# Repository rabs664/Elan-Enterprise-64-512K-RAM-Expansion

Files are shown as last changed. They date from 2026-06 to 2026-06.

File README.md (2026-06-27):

# Elan-Enterprise-64-512K-RAM-Expansion

512K EP RAM

>[!CAUTION]
>USE AT YOUR OWN RISK.
>There is always the risk that this 512k RAM Expansion could cause harm to your Enterprise. Although I have tested the 512K RAM Expansion, there is no guarantee that it will work properly under all circumstances.
>
>I am not an Enterprise Expert and still learning about this machine. What you see here is an intepretation of what I have found on the web, see the acknowledgements.

>[!WARNING]
>There is not a lot of room under the keyboard and the jumper wire connectors are a tight fit. There is probably a better solution to this.
>
> Also the EXP1 connector does not have standard spacing and you have to use two separate headers.
>
> 

## Project History
### 27 June 2026
First Releae

## Acknowledgements
- [Supid Humans Inc EP RAM](https://github.com/StupidHumansInc/EP_RAM)
- [Andra Santos](https://github.com/andrastantos/enterprise_mem_extender)

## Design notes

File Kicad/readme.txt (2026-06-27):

This folder contains the Kicad project files and gerbers.

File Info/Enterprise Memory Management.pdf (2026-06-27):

The Enterprise has a 22-bit address space (A0 to A21) giving 4MB of addressable space!

The Z80 address space is divided into 16KB “Pages” (numbered 0-3) where A14 and A15 select four 8-bit “Segment” registers in “DAVE”.

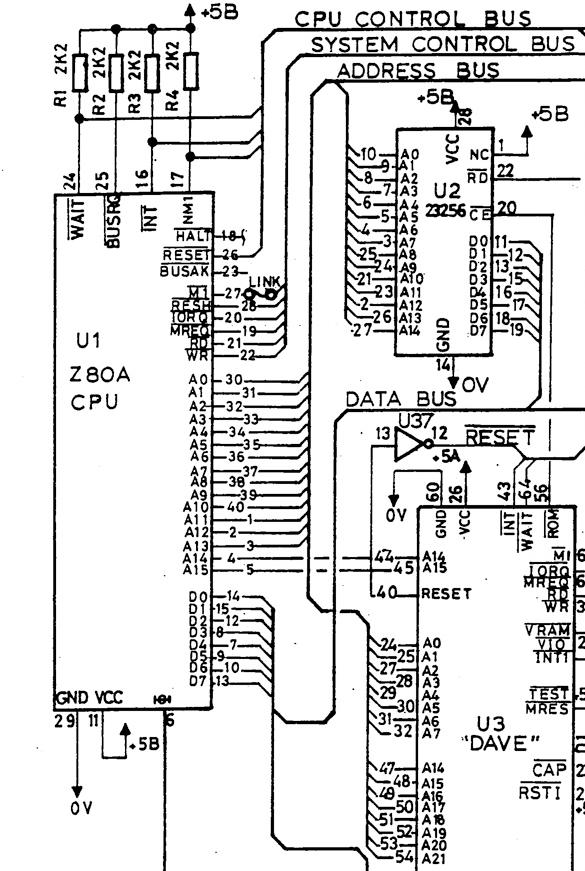
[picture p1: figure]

The Enterprise 4MB address space is divided into 256 16K “segments”. Each “Segment” has a number, 00h-FFh.

A0-A13 + 8-bits, from the “Segment” registers, generate the 22-bit address.

Certain “Segments” are predefined

Internal 32K ROM | 00h-01h
64K Cartridge Slot | 04h-07h
Internal 64K DRAM | FCh-FFh
2 nd Internal 64K DRAM | F8h-FBh

There is Z80 I/O port associated with each “Segment” register in “DAVE” which allows the “Segment” number to be set for each “page”.
Page | Address | Port
0 | 0000h-3FFFh | B0h
1 | 4000h-7FFFh | B1h
2 | 8000h-BFFFh | B2h
3 | C000h-FFFFh | B3h

Any “Segment” can be mapped to any “Page” by writing the “Segment” number to the IO port for the respective “Page”.

Using 512KB SRAM (AS6C4008) with 19 address lines (A0 to A18), the “Segments” are as below;

Segment | A21 | A20 | A19 | A18 | A17 | A16 | A15 | A14 | Note
FF | 1 | 1 | 1 | 1 | 1 | 1 | 1 | 1 | Internal DRAM
FE | 1 | 1 | 1 | 1 | 1 | 1 | 1 | 0 | Internal DRAM
FD | 1 | 1 | 1 | 1 | 1 | 1 | 0 | 1 | Internal DRAM
FC | 1 | 1 | 1 | 1 | 1 | 1 | 0 | 0 | Internal DRAM
FB | 1 | 1 | 1 | 1 | 1 | 0 | 1 | 1 | 512K SRAM
FA | 1 | 1 | 1 | 1 | 1 | 0 | 1 | 0 | 512K SRAM
F9 | 1 | 1 | 1 | 1 | 1 | 0 | 0 | 1 | 512K SRAM
F8 | 1 | 1 | 1 | 1 | 1 | 0 | 0 | 0 | 512K SRAM
F7 | 1 | 1 | 1 | 1 | 0 | 1 | 1 | 1 | 512K SRAM
F6 | 1 | 1 | 1 | 1 | 0 | 1 | 1 | 0 | 512K SRAM
F5 | 1 | 1 | 1 | 1 | 0 | 1 | 0 | 1 | 512K SRAM
F4 | 1 | 1 | 1 | 1 | 0 | 1 | 0 | 0 | 512K SRAM
F3 | 1 | 1 | 1 | 1 | 0 | 0 | 1 | 1 | 512K SRAM
F2 | 1 | 1 | 1 | 1 | 0 | 0 | 1 | 0 | 512K SRAM
F1 | 1 | 1 | 1 | 1 | 0 | 0 | 0 | 1 | 512K SRAM
F0 | 1 | 1 | 1 | 1 | 0 | 0 | 0 | 0 | 512K SRAM
EF | 1 | 1 | 1 | 0 | 1 | 1 | 1 | 1 | 512K SRAM
EE | 1 | 1 | 1 | 0 | 1 | 1 | 1 | 0 | 512K SRAM
ED | 1 | 1 | 1 | 0 | 1 | 1 | 0 | 1 | 512K SRAM
EC | 1 | 1 | 1 | 0 | 1 | 1 | 0 | 0 | 512K SRAM
EB | 1 | 1 | 1 | 0 | 1 | 0 | 1 | 1 | 512K SRAM
EA | 1 | 1 | 1 | 0 | 1 | 0 | 1 | 0 | 512K SRAM
E9 | 1 | 1 | 1 | 0 | 1 | 0 | 0 | 1 | 512K SRAM
E8 | 1 | 1 | 1 | 0 | 1 | 0 | 0 | 0 | 512K SRAM
E7 | 1 | 1 | 1 | 0 | 0 | 1 | 1 | 1 | 512K SRAM
E6 | 1 | 1 | 1 | 0 | 0 | 1 | 1 | 0 | 512K SRAM
E5 | 1 | 1 | 1 | 0 | 0 | 1 | 0 | 1 | 512K SRAM
E4 | 1 | 1 | 1 | 0 | 0 | 1 | 0 | 0 | 512K SRAM
E3 | 1 | 1 | 1 | 0 | 0 | 0 | 1 | 1 | 512K SRAM
E2 | 1 | 1 | 1 | 0 | 0 | 0 | 1 | 0 | 512K SRAM
E1 | 1 | 1 | 1 | 0 | 0 | 0 | 0 | 1 | 512K SRAM
E0 | 1 | 1 | 1 | 0 | 0 | 0 | 0 | 0 | 512K SRAM
DF | 1 | 1 | 0 | 1 | 1 | 1 | 1 | 1 | 512K SRAM
DE | 1 | 1 | 0 | 1 | 1 | 1 | 1 | 0 | 512K SRAM
DD | 1 | 1 | 0 | 1 | 1 | 1 | 0 | 1 | 512K SRAM
DC | 1 | 1 | 0 | 1 | 1 | 1 | 0 | 0 | 512K SRAM
DB | 1 | 1 | 0 | 1 | 1 | 0 | 1 | 1 | No SRAM

Note DF-DC maps over the Internal DRAM “Segments” but with A19 low.

Decoded Address Line signals to drive CE on the 512KB SRAM are as follows; (A21 & A20 & A19 & A18 & A17 & !A16)

# (A21 & A20 & A19 & A18 & !A17)

# (A21 & A20 & A19 & !A18)

# (A21 & A20 & !A19 & A18 & A17 & A16)

Additionally, the Control Lines for a Memory Request and excluding Refresh cycles are required.

!MREQ & REFSH
ChatGPT reduced this but it is easier to follow the above.
!CE=A21 & A20 & !MREQ & RFSH & (A19 & !A18 # A19 & /A17 # A19 & /A16 # /A19 &A18 & A17 &A16)

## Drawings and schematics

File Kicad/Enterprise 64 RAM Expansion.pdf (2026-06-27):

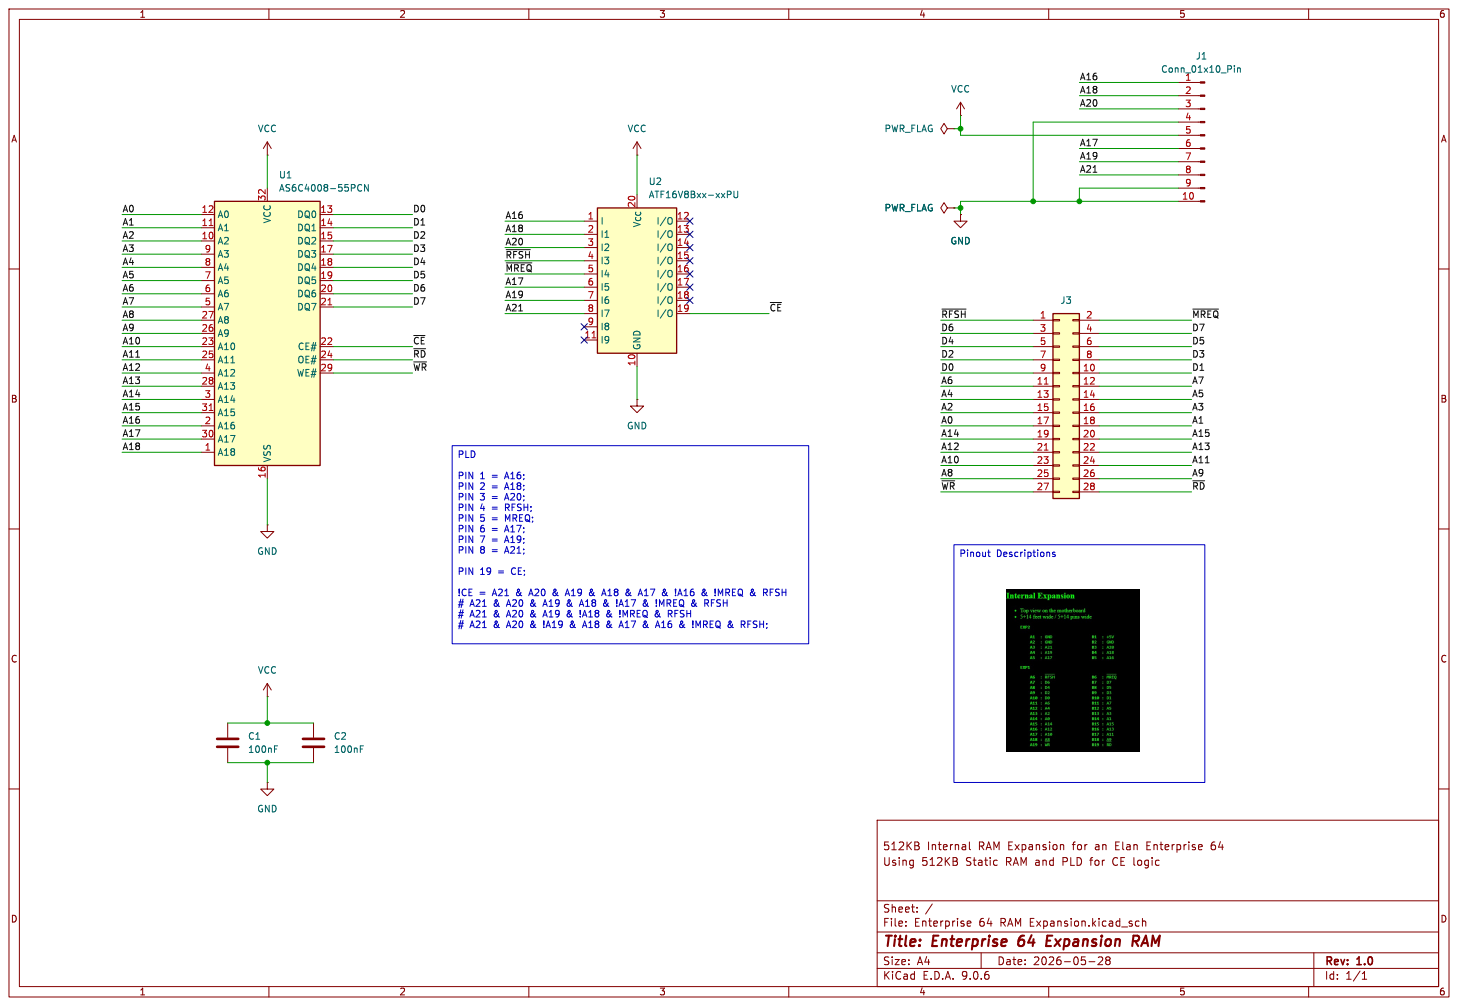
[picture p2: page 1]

PIN 1 = A16; PIN 2 = A18; PIN 3 = A20; PIN 4 = RFSH; PIN 5 = MREQ; PIN 6 = A17; PIN 7 = A19; PIN 8 = A21; PIN 19 = CE;

Id: 1/1 Title: Enterprise 64 Expansion RAM

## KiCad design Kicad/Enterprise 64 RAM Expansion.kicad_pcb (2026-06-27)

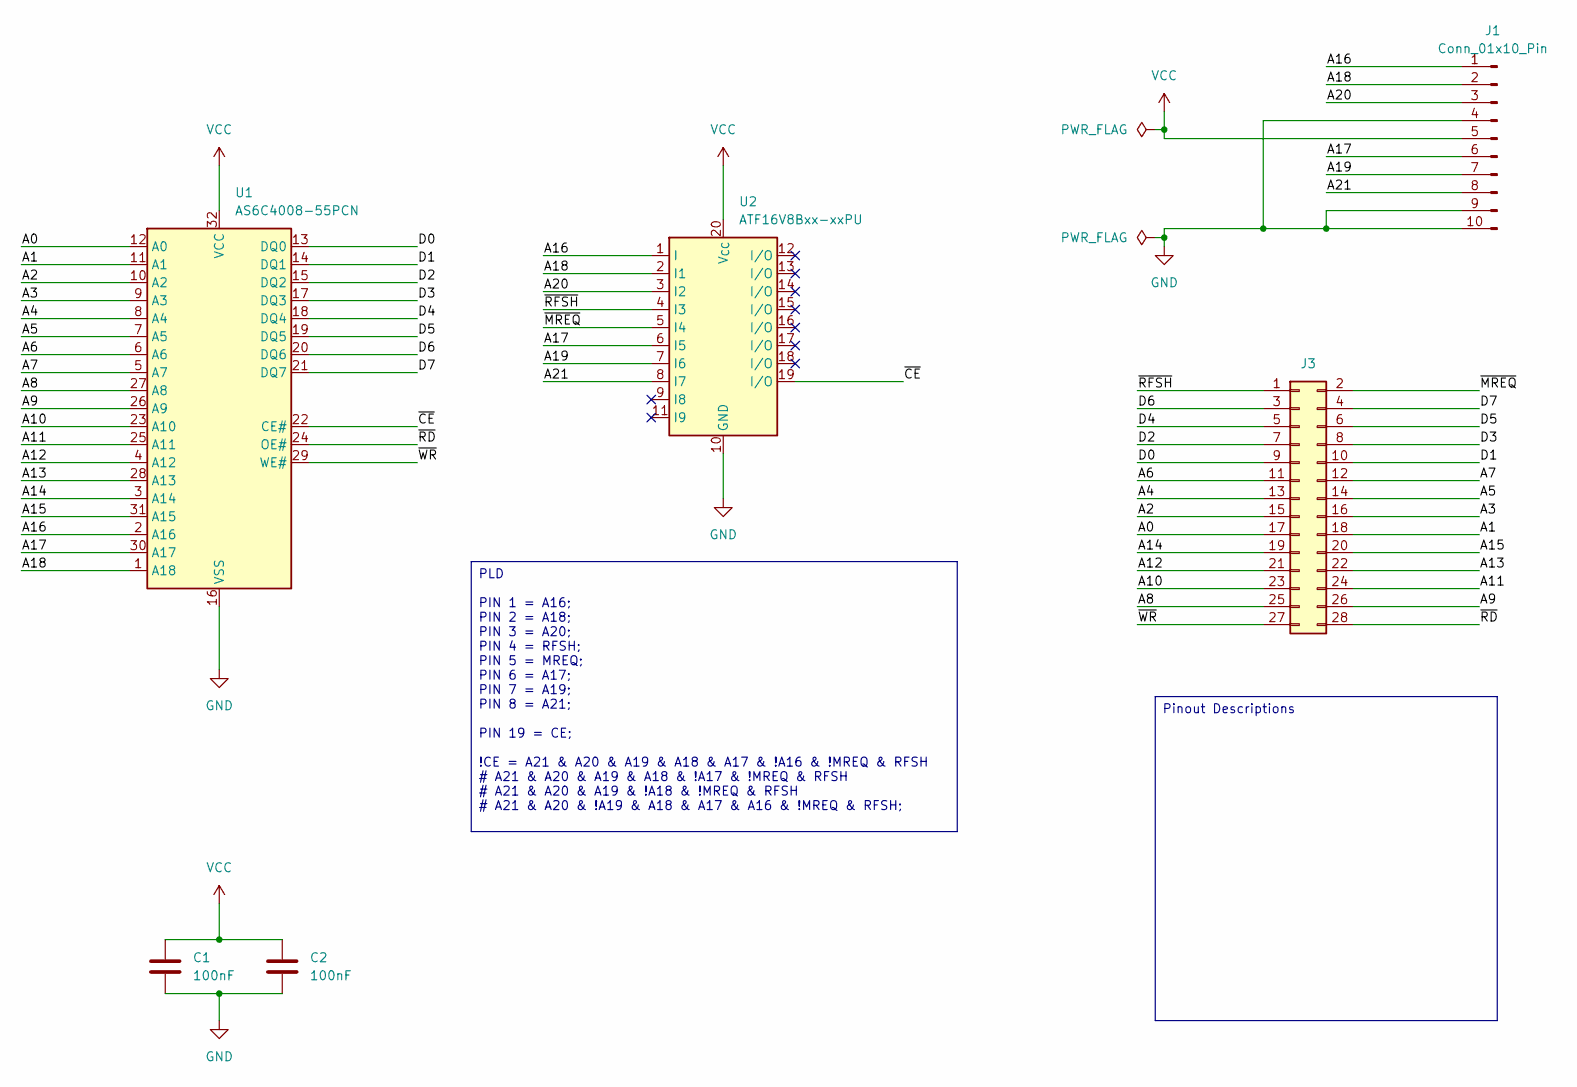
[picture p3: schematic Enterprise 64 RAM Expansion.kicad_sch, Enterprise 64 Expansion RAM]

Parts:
C1, C2: 100nF; C_0805_2012Metric_Pad1.18x1.45mm_HandSolder
J1: Conn_01x10_Pin; PinHeader_1x10_P2.54mm_Horizontal
J3: Conn_02x16_Row_Letter_First; PinSocket_2x14_P2.54mm_Vertical
U1: AS6C4008-55PCN; SOP-32_11.305x20.495mm_P1.27mm
U2: ATF16V8Bxx-xxPU; SOIC-20W_7.5x12.8mm_P1.27mm

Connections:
/A0: J3.17, U1.12 (A0)
/A1: J3.18, U1.11 (A1)
/A2: J3.15, U1.10 (A2)
/A3: J3.16, U1.9 (A3)
/A4: J3.13, U1.8 (A4)
/A5: J3.14, U1.7 (A5)
/A6: J3.11, U1.6 (A6)
/A7: J3.12, U1.5 (A7)
/A8: J3.25, U1.27 (A8)
/A9: J3.26, U1.26 (A9)
/A10: J3.23, U1.23 (A10)
/A11: J3.24, U1.25 (A11)
/A12: J3.21, U1.4 (A12)
/A13: J3.22, U1.28 (A13)
/A14: J3.19, U1.3 (A14)
/A15: J3.20, U1.31 (A15)
/A16: J1.1, U1.2 (A16), U2.1 (I)
/A17: J1.6, U1.30 (A17), U2.6 (I5)
/A18: J1.2, U1.1 (A18), U2.2 (I1)
/A19: J1.7, U2.7 (I6)
/A20: J1.3, U2.3 (I2)
/A21: J1.8, U2.8 (I7)
/D0: J3.9, U1.13 (DQ0)
/D1: J3.10, U1.14 (DQ1)
/D2: J3.7, U1.15 (DQ2)
/D3: J3.8, U1.17 (DQ3)
/D4: J3.5, U1.18 (DQ4)
/D5: J3.6, U1.19 (DQ5)
/D6: J3.3, U1.20 (DQ6)
/D7: J3.4, U1.21 (DQ7)
/~CE: U1.22 (CE#), U2.19 (I/O)
/~MREQ: J3.2, U2.5 (I4)
/~RD: J3.28, U1.24 (OE#)
/~RFSH: J3.1, U2.4 (I3)
/~WR: J3.27, U1.29 (WE#)
GND: C1.2, C2.2, J1.4, J1.9, J1.10, U1.16 (VSS), U2.10 (GND)
VCC: C1.1, C2.1, J1.5, U1.32 (VCC), U2.20 (V_{CC})

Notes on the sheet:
Pinout Descriptions
PLD PIN 1 = A16; PIN 2 = A18; PIN 3 = A20; PIN 4 = RFSH; PIN 5 = MREQ; PIN 6 = A17; PIN 7 = A19; PIN 8 = A21; PIN 19 = CE; !CE = A21 & A20 & A19 & A18 & A17 & !A16 & !MREQ & RFSH # A21 & A20 & A19 & A18 & !A17 & !MREQ & RFSH # A21 & A20 & A19 & !A18 & !MREQ & RFSH # A21 & A20 & !A19 & A18 & A17 & A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

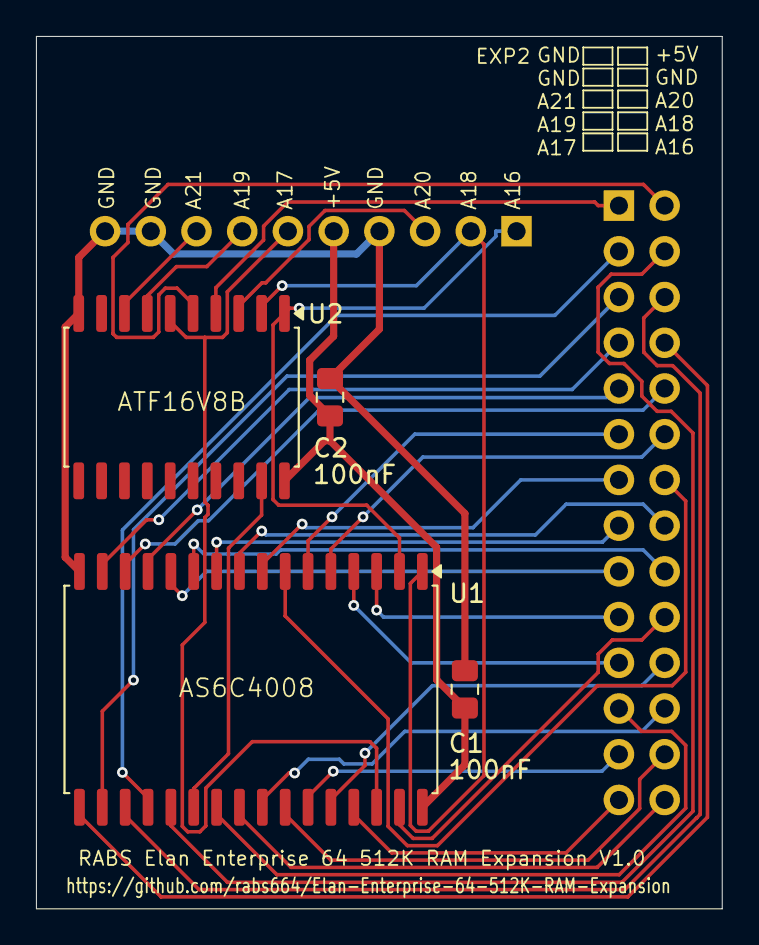
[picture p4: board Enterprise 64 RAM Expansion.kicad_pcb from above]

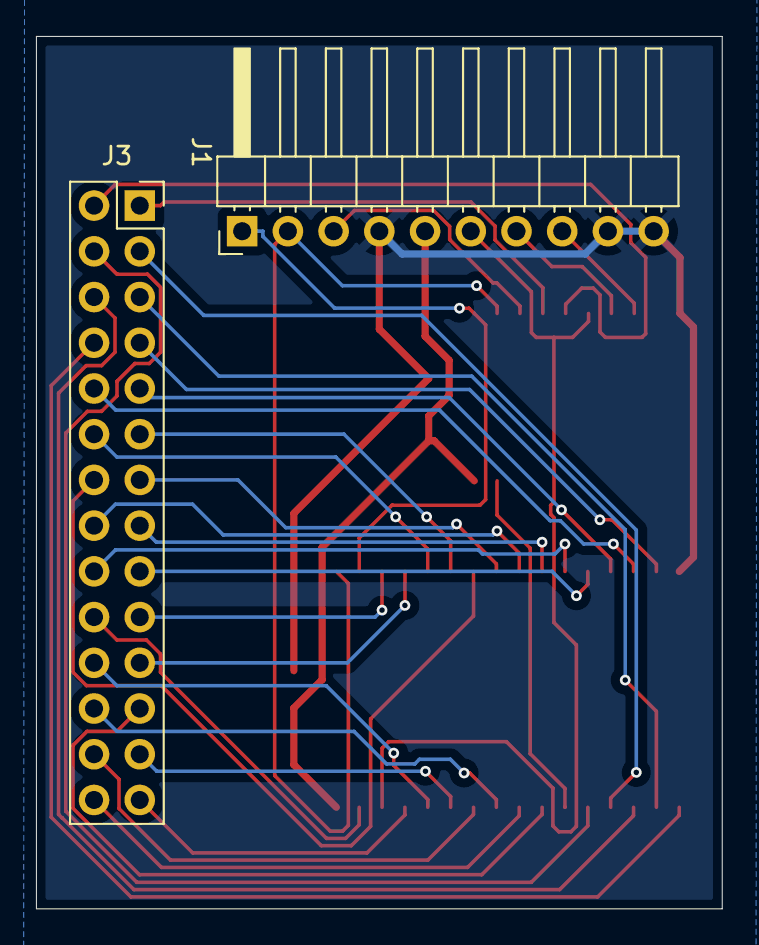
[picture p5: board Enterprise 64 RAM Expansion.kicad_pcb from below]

Board: 2 copper layers, 38.1 x 48.5 mm, 6 parts (2 on the bottom side), 37 nets.
